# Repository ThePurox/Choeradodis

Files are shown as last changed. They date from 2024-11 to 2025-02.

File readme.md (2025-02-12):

# Choeradodis
The Choeradodis is an ultra low profile version of the [Hexapoda](https://github.com/ThePurox/Hexapoda), which itself is based on the [hummingbird](https://github.com/PJE66/hummingbird) style 30 key keyboard. It is designed around [hexagonal keycaps](https://hw.s-ol.nu/HEX-keycaps/), and Cherry's ultra low profile switches (mx6c-k3nb and mx6c-t3nb).
It uses the CH552T controller and [FAK firmware](https://github.com/semickolon/fak).
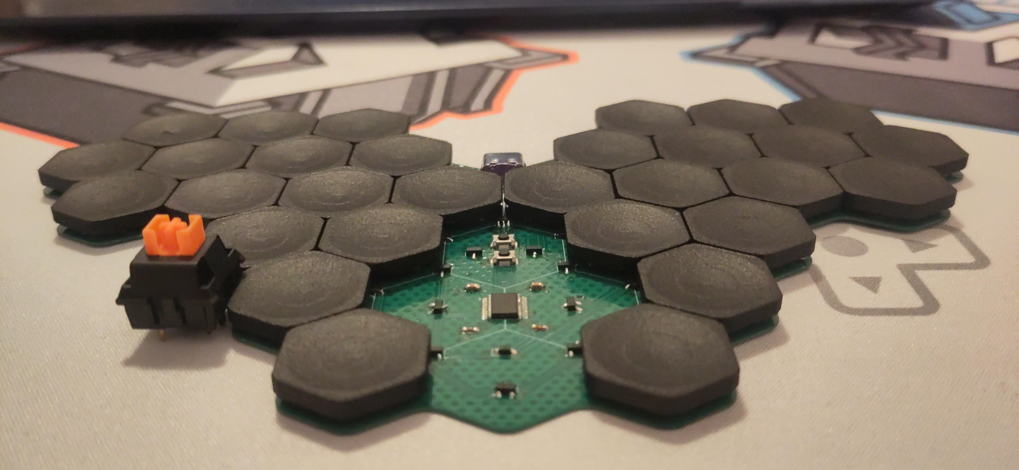
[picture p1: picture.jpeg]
top view of keyboard


The electronic design is inspired by the [MIAO MCU board](https://github.com/kilipan/miao).

# Buildguide
Soldering should be straight forward with the help of the [interactive bill of materials](bom/ibom.html)
The orientation of `U1` and `U2` are indicated by small arrows on the PCB.
The orientaion `D16` is such that its white line is on the side where the footprint on the silkscreen also has a white line.
For all other components, the orientation does not matter, or their form-factor allows only one orientation (`D1-D15`).
Make sure to also solder the metal legs on the side, as they will give stability to the jack.
Do **not** plug in a USB-cabel without soldering the metal legs on the side of the USB-jack! You will most likely rip off the USB-jack when unplugging the USB-cable!

# Flashing firmware
This keyboard is designed for the [FAK-firmware](https://github.com/semickolon/fak).
I've provided some example configuration files in [my fork](https://github.com/ThePurox/fak-config) of the fak-config repository with the keyboard name `hexapoda`.
The push-button closer to the USB-jack is the `BOOT` button. The one closer to the thumb keys is the `RESET` button.

# Keycaps
The files to generate the `.stl`s for the keycaps can be found in this [keycaps](keycaps).
Generate a spruce of the keycaps by running the [openscad](https://openscad.org/) script and exporting a `stl` of them.
Then print the resulting file. I got my caps printed at JLC in MJF.
The keycaps in the middle of the PCB will collide with the electronic components, so you need to trim their corners and the edges of the upper inner pindex finger keys. This can easily be done with wire cutters.
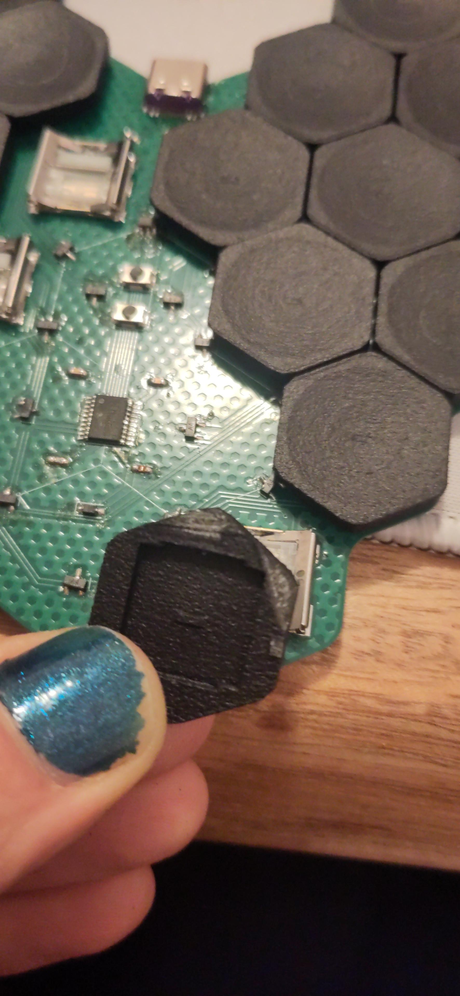
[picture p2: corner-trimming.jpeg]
Image of trimmed keycaps


# BOM
| Part | LCSC-Part Nr | amount |
|---|---|---|
| USB-C | C2765186 | 1 |
| CH552T | C111367 | 1 |
| BAV70 Diodes | C727123 | 15 |
| USBLC6-2SC6 | C6807798 | 1 |
| PMEG2010EA | C193668 | 1 |
| Push buttons | C115357 | 2 |
| Fuse | C311055 | 1 |
| 5.1k-Resistor | C23186 | 2 |
| 10k-Resistor | C25804 | 1 |
| 1uF-Capacitor | C2991434 | 2 |
| Cherry ULP Switches | | 30 |
| Cherry ULP Keycaps  | | 30 |

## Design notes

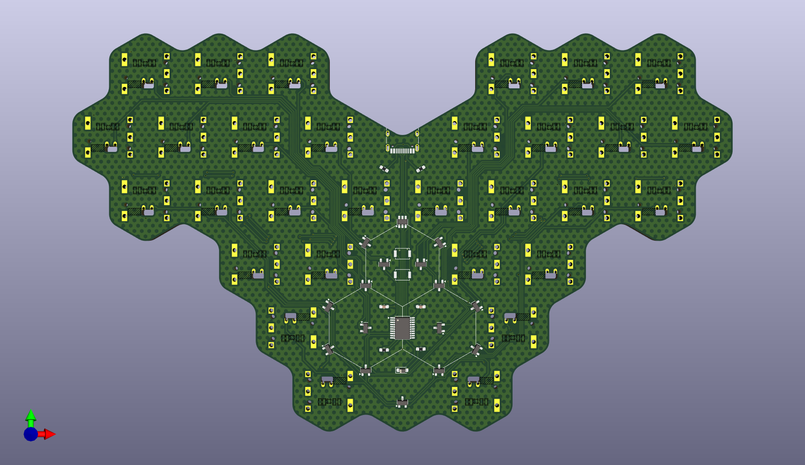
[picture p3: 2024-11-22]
front.png

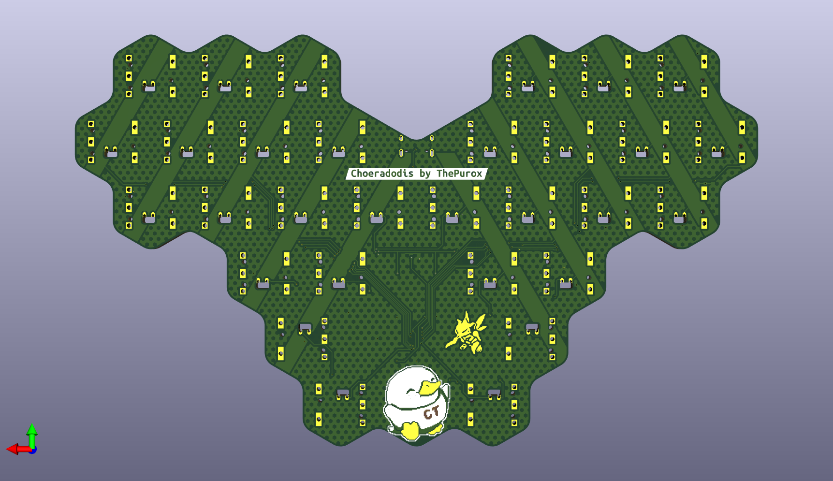
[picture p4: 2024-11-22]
back.png

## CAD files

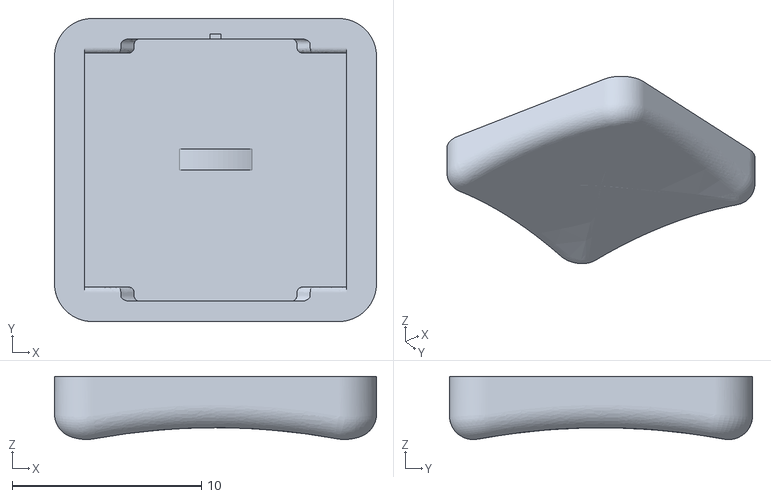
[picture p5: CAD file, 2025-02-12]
keycaps/MX_ULP_Keycap_fixed.stl
17.0 x 16.0 x 3.33

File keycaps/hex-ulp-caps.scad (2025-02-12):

//a=21.5-0.54; // spacing - gap
a=21.5-0.74; // spacing - gap
r=a/2/cos(30);
ri=9.5;
hi = 1.;
h_cap=3;
Rs = (ri*ri+hi*hi)/(2*hi);
//$fn=100;

h_sq=2.45;
h_sq_f=1.9;

module hex_ulp(){

//translate([100,100,100])
difference(){
    minkowski(){
        translate([0,0,0])cylinder(r=r-3.25,h=h_cap,$fn=6);
        cylinder(r=3,h=0.01);
    }
    translate([0,0,Rs+h_cap-hi])sphere(Rs,$fn=1000);
    translate([0,0,h_sq/2-0.75])cube([14.35,14.35,h_sq],center=true);

}
difference(){
    translate([0,0,h_sq_f])color("red")rotate([180,0,90])import("MX_ULP_Keycap_fixed.stl");
    translate([0,0,2.75])cube([18,18,2],center=true);
}
}
dx = 25;
dy = 23;

for(i=[0:4]){
    for(j=[0:1]){
        translate([j*dx,i*dy,0]){
            hex_ulp();
            if(i<4)translate([0,a/2-1.5,-2])cube([2,5,2]);
            if(j<1)translate([a/2-0.5,0,-2])cube([5,2,2]);
        }       
    }
}

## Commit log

2025-01-25 fixed missing gnd connection
2025-02-12 added keycaps
    [MX_ULP_Keycap_fixed.stl, hex-ulp-caps.scad]
